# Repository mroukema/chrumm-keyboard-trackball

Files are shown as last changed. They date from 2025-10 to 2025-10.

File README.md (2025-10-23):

Chrumm Trackball Keyboard
===============

Chrumm Trackball is a fork of the original [Chrumm open-hardware ergonomic keyboard](https://github.com/sevmeyer/chrumm-keyboard).

This fork adds more aggressive key stagger as per my own personal preference, a second row of choc thumb keys and a trackball + mouse buttons. The encoder has been dropped. The changes made make this version incompatible with the old PCB and is now handwired with per key PCBs + a Elite-pi microcontroller. The microcontroller has been moved to the case edge so that the usb-c port is outwardly accessible removing the need for a usb-c male-female adapter cable. Finally a outwardly accessible run button has been added for convinence

I've included the python changes made to generate the second row of thumb keys but please note that there are plenty of manual editing of 3d objects post generation in order to convert the keys to choc compatible mounts, add the trackball and mouse keys and chnage the MCU mount. 

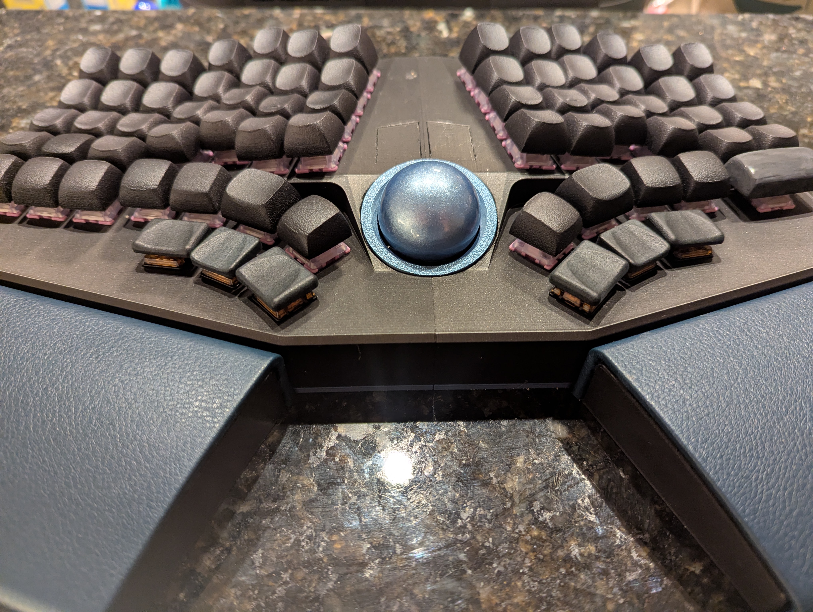
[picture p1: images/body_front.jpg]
Front view of the finished keyboard


Inside view with installed electronics

Files
-----

- [BUILD.md](BUILD.md) - Build advice
- [MATERIALS.md](MATERIALS.md) - Bill Of Materials
- [body/README.md](body/README.md) - Body generator parameters

Features
--------

Chrumm features a column staggered layout with two row thumb clusters.
The left side has an additional column, to provide dedicated arrow keys.

The body is a robust monoblock without visible screws. It has
integrated split, tent, and tilt angles, similar to commercial
ergonomic boards. The palm rests are firmly
attached, so that everything can be moved around without hassle.

The starting point STL files are generated programmatically, with a pure
Python package that has no dependencies. This fork has heavily modified the STLs post generation however.

Layout
------

Default logical layout with two layers

Firmware
------
Assoiciated firmware can be found on [my QMK fork](https://github.com/mroukema/qmk_firmware/tree/chrumm-trackball)

Credit
------

This keyboard is a fork of the original [Chrumm open-hardware ergonomic keyboard](https://github.com/sevmeyer/chrumm-keyboard) without which this board would not exist.

Trackball mount is modified starting from the [Charybdis veichu mod](https://github.com/Bastardkb/Charybdis/tree/main/files/mods/veichu) and [adapter ring](https://github.com/Bastardkb/Charybdis/blob/main/files/3x5%20nano/adapter_v2_top_v75.stl)

Gallery
-------

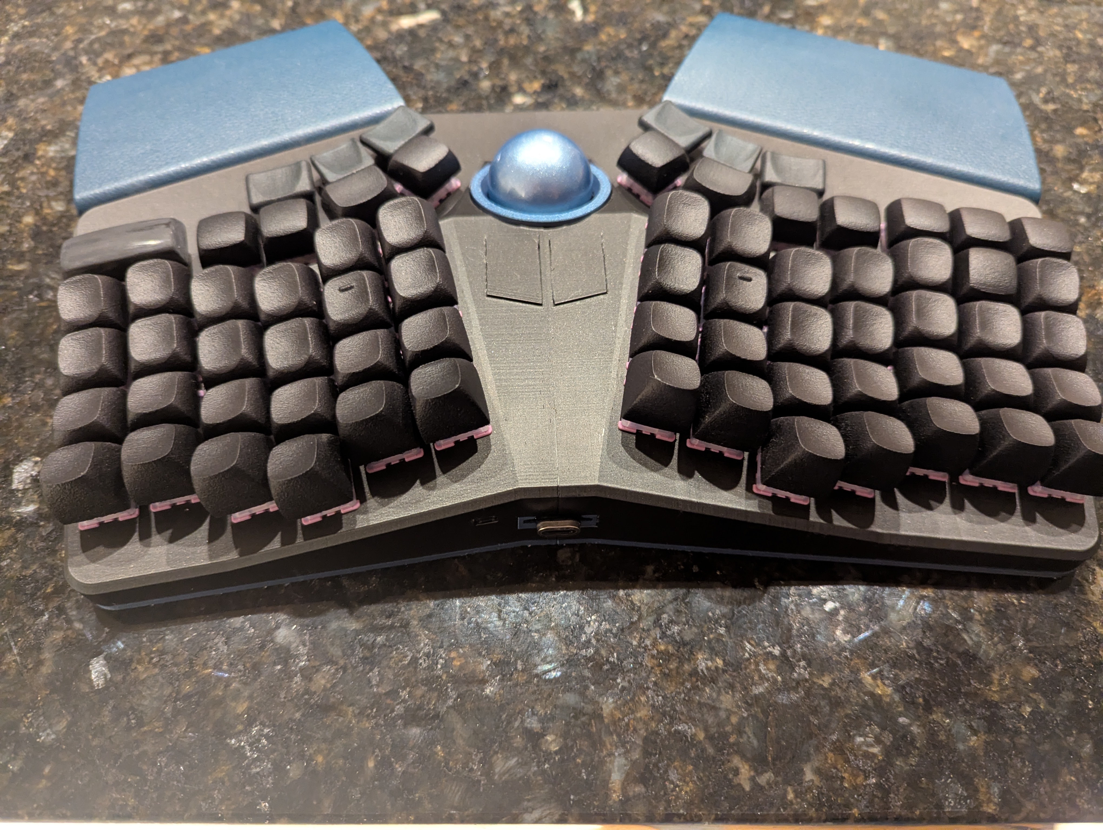
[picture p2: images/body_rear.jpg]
Rear View

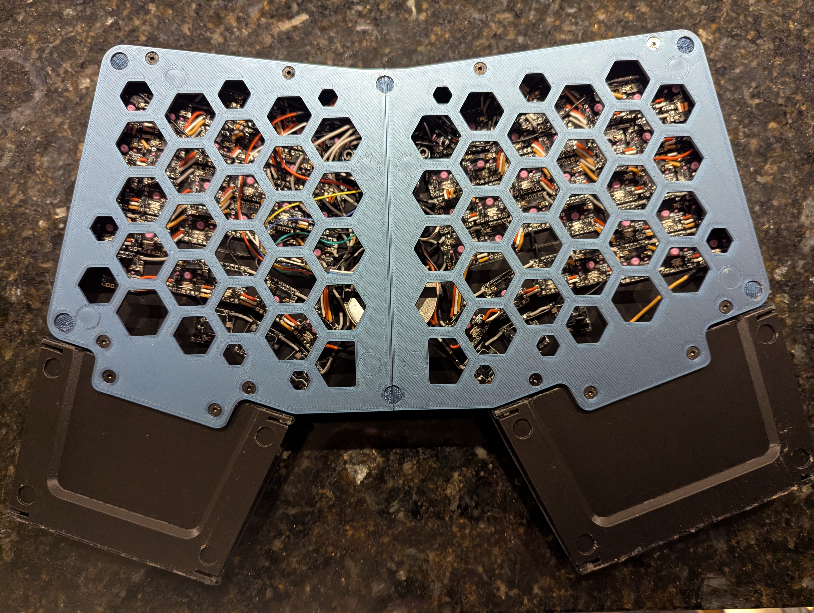
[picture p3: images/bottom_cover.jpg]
Bottom View


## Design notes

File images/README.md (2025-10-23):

Front view
Inside view with installed electronics
Rear View
Bottom View

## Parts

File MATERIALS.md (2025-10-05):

Chrumm Trackball Bill Of Materials
========================

Mechanical
----------

- 12x Threaded insert, M3, 4mm hole diameter, max 5.7mm length
- 12x Countersunk screw, M3, 8mm total length, ISO 10642
-  8x Hex nut with nylon insert, M3, ISO 10511
-  2x Hex nut with nylon insert, M2
-  8x Socket head cap screw, M3, 8mm thread length, ISO 4762 (*)
-  2x Socket head cap screw, M2, 6mm thread length, ISO 4762
- 14x 3M Bumpon SJ5302, hemispherical, 8mm diameter, 2mm height
-  2x Artificial leather, ~195x130mm, max 1.2mm thickness
- Glue for artificial leather on printed filament
- Keycaps (64 mx + 6 choc v1)
- 8x 8x3mm Neodymium magnets (optional for magnetic base plate)
- 3x Veichu YK310/311 BTU bearings
- 1x 34mm Trackball
(*) Some of the screws are difficult to reach and
require a ball-point driver, or a short-armed key.

Electronic
----------

-  1x Elite-Pi Microcontroller or equivelent 
- 70x Diode Surface mount diodes
- 64x SK6812Mini LEDs
- ~500ohm resistor
- ~500 µF Capacitor 
- 64x amoeba royal or other per key PCBs for MX switches
-  6x [enigma-dual-hs](https://github.com/mroukema/enigma-dual-hs) per key PCBs  or other choc compatible per key PCBs
- 64x MX switch
-  6x choc switch
-  1x PMW3389 Trackball Sensor × 1 mount compatible with ([Good Great Grand Wonderful PCB](https://ergokeyboards.com/products/pmw3360-trackball-sensor-upgrade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))
-  2x Omron D2F Mouse Switch
-  1x Tactile Switch
-  Electrial Wire

3D-printed
----------

-  2x Body half (left, right)
-  2x Floor half (left, right)
-  2x Palm rest (left, right)
-  1x MCU Mounting Plate
-  1x Trackball Veichu BTU Bearing Base
-  1x Trackball Top Ring

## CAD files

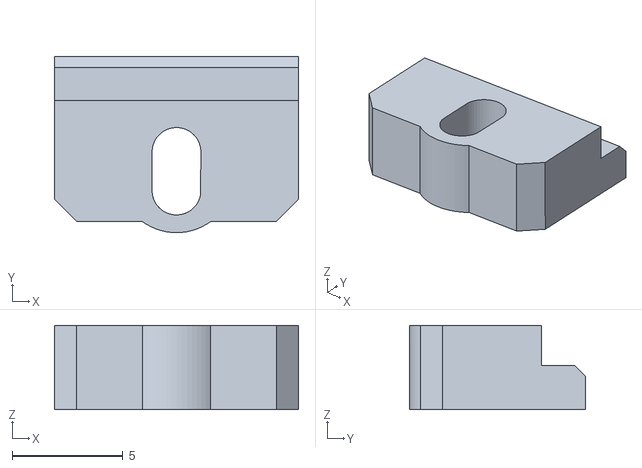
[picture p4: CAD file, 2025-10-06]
body/chrumm-mcu-adjustable-stuck.stl
11.0 x 7.95 x 3.80

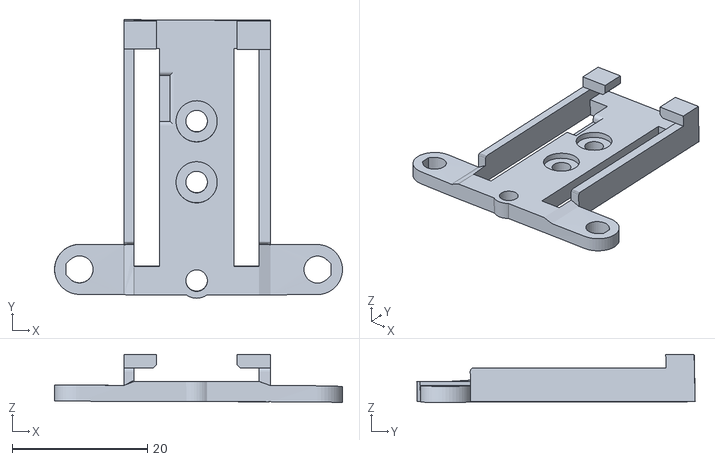
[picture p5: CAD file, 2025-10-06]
body/chrumm-trackball-mcu-mount.stl
42.6 x 41.2 x 7.10

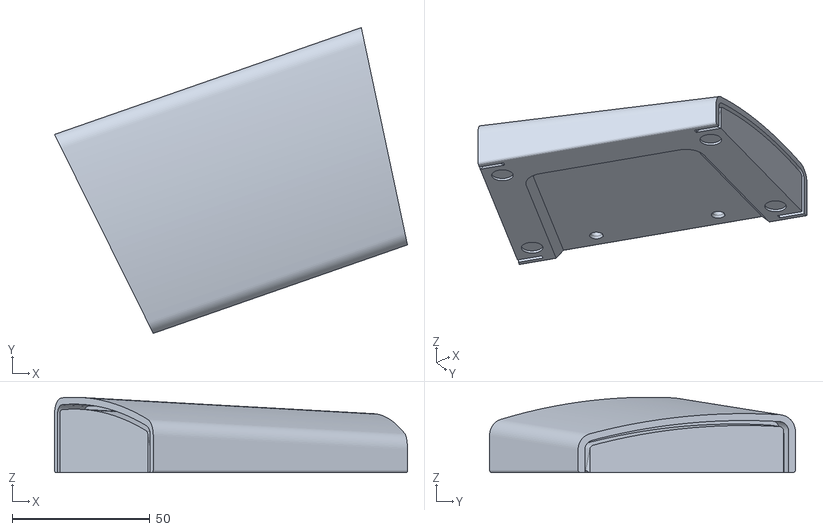
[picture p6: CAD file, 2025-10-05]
body/chrumm-trackball-palm-right.stl
128.1 x 111.0 x 27.4

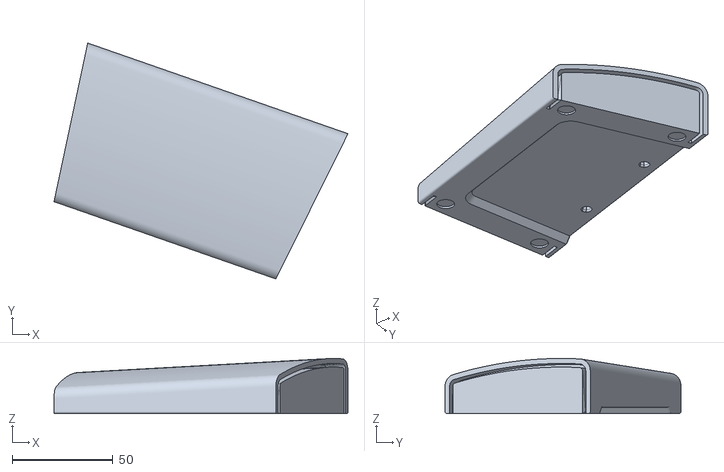
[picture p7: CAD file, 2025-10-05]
body/chrumm-trackball-palm-left.stl
146.2 x 117.3 x 27.4

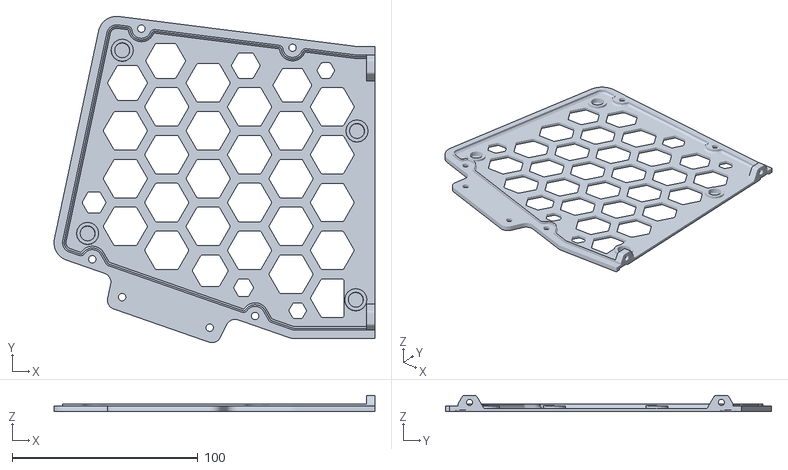
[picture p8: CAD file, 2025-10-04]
body/chrumm-trackball-floor-left.stl
173.0 x 175.9 x 8.77

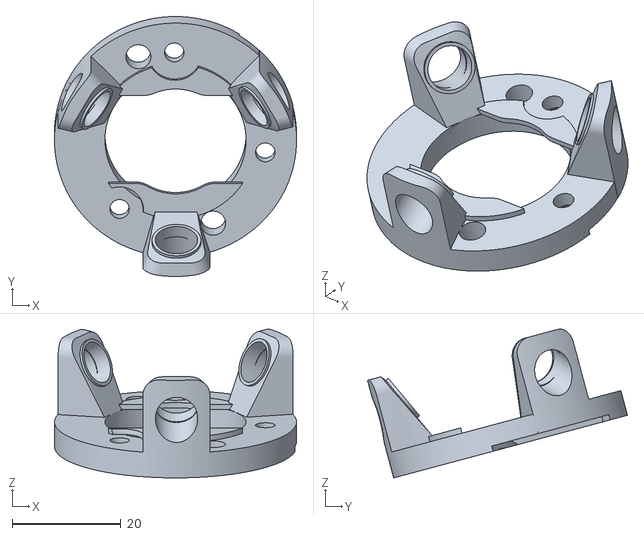
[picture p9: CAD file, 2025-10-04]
body/chrumm-trackball-veichu.stl
44.6 x 47.9 x 27.4

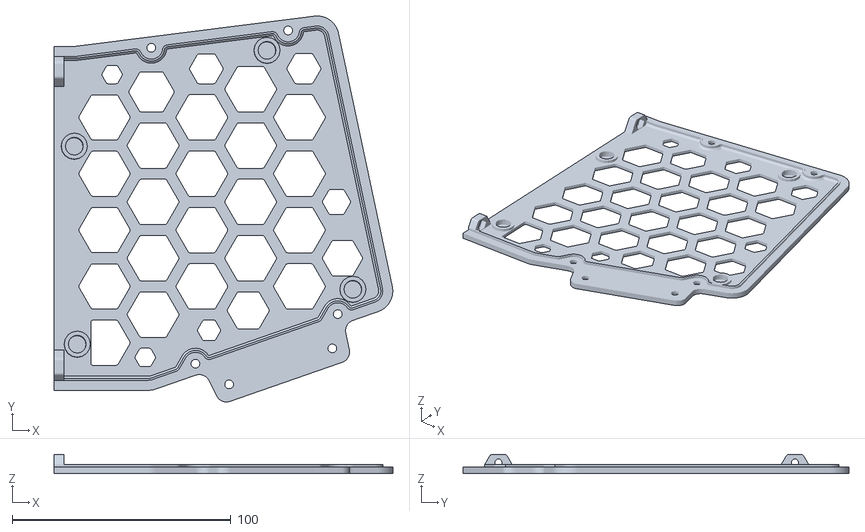
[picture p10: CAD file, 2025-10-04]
body/chrumm-trackball-floor-right.stl
155.0 x 176.6 x 8.77

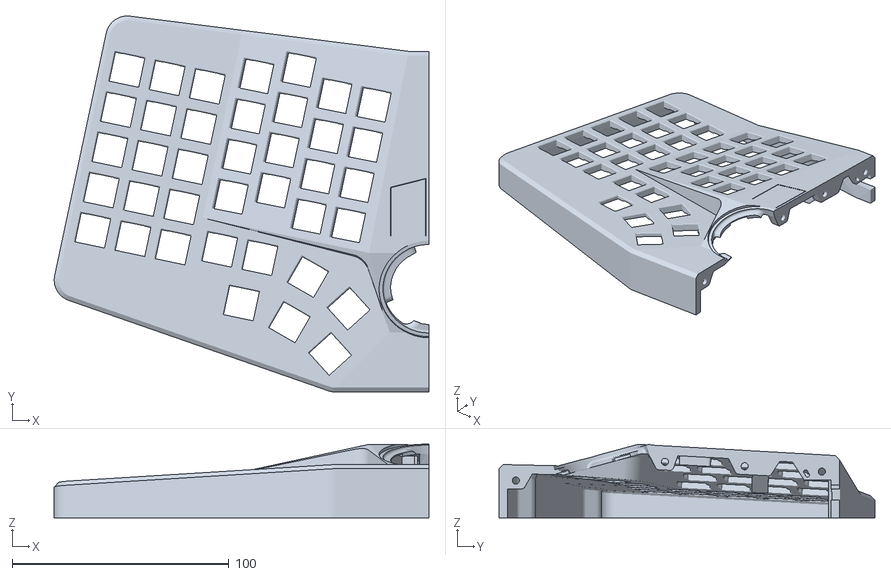
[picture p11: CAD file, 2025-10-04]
body/chrumm-trackball-body-left.stl
173.0 x 173.7 x 34.1

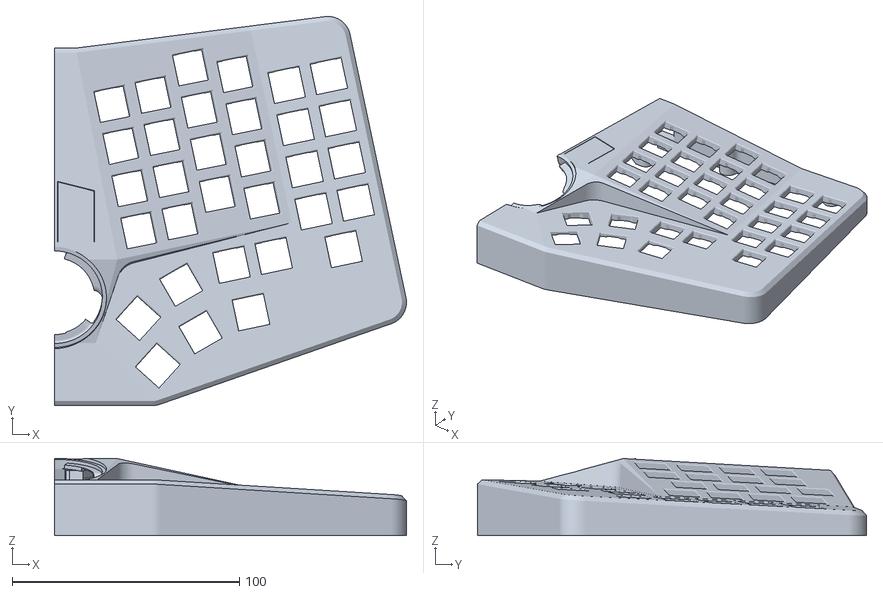
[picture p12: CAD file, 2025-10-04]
body/chrumm-trackball-body-right.stl
155.0 x 171.3 x 34.1

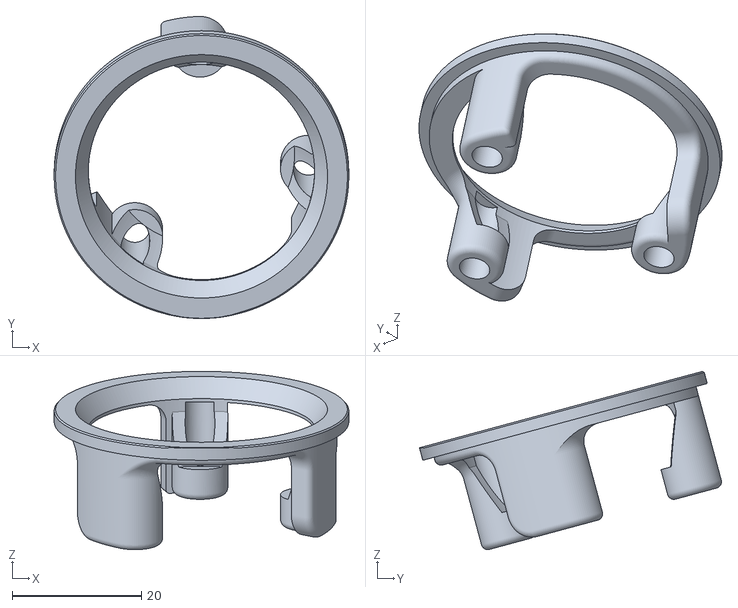
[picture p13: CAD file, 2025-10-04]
body/chrumm-trackball-ring-adapter.stl
45.6 x 46.7 x 27.6

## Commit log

2025-10-04 Remove the PCB as it is not compatible with modified keyboard
    [chrumm.kicad_pcb, chrumm.kicad_sch]
2025-10-04 Update BOM
2025-10-04 Remove prusa config since it won't be compatible with modified board
2025-10-04 Add stls since the completed keyboard in this fork cannot be purly generated
    [chrumm-trackball-body-left.stl, chrumm-trackball-body-right.stl, chrumm-trackball-floor-left.stl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]
2025-10-05 Add tactile switch to BOM
2025-10-05 Mirror left/right palm
    [chrumm-trackball-palm-left.stl, chrumm-trackball-palm-right.stl]
2025-10-05 Add allowance for jumpers on Elite-pi to be soldered on mcu mount
    [chrumm-trackball-mcu-mount.stl]
2025-10-06 Add mcu stopper and minor adjustments to mcu mount
    [chrumm-mcu-adjustable-stuck.stl, chrumm-trackball-mcu-mount.stl]
